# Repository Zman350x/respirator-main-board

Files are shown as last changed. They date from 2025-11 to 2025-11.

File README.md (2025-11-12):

# Respirator Main Board PCB
## Description

Controls the fans of an active respirator, with added user interface and
various indicators. Made for Intro Engineering Design final project, Fall 2025.

## Pictures

Layout:

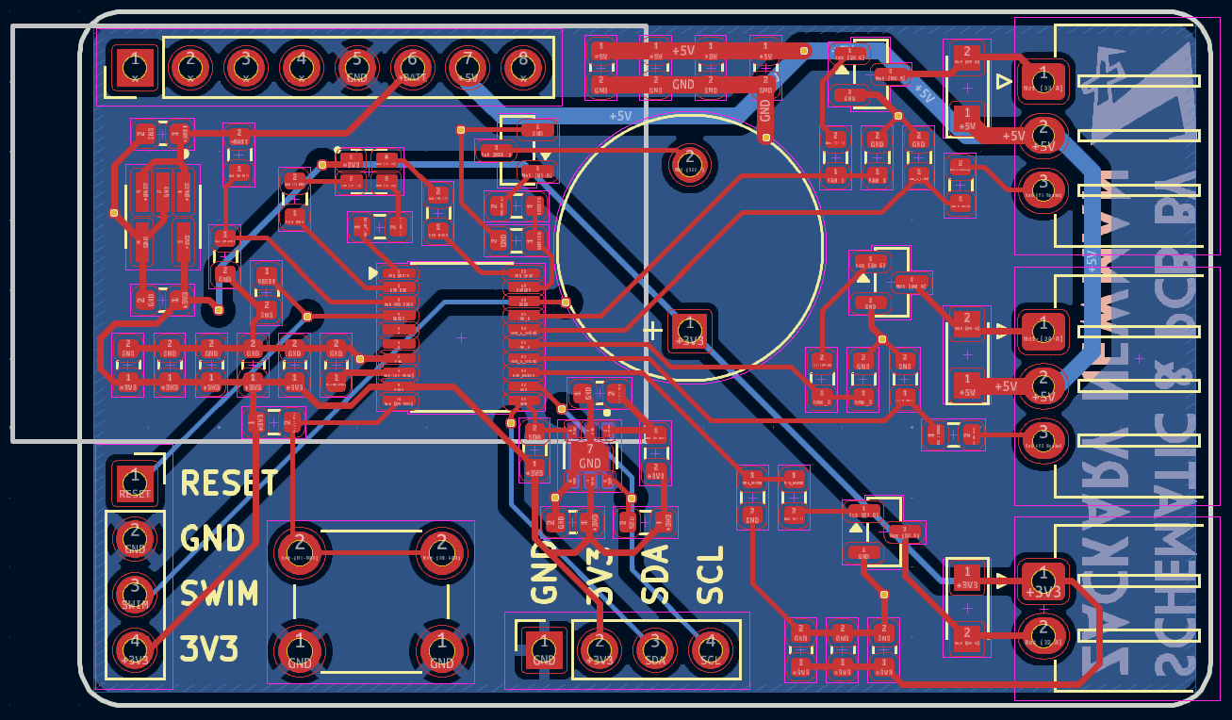
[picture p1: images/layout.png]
Layout


3D Render:

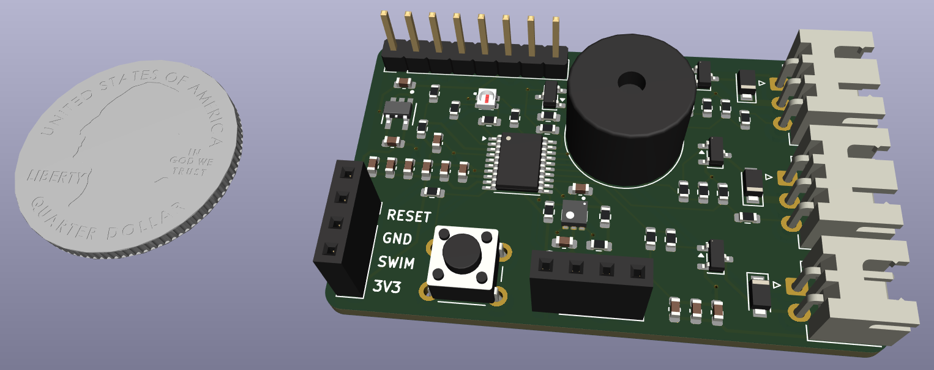
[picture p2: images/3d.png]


Schematic:

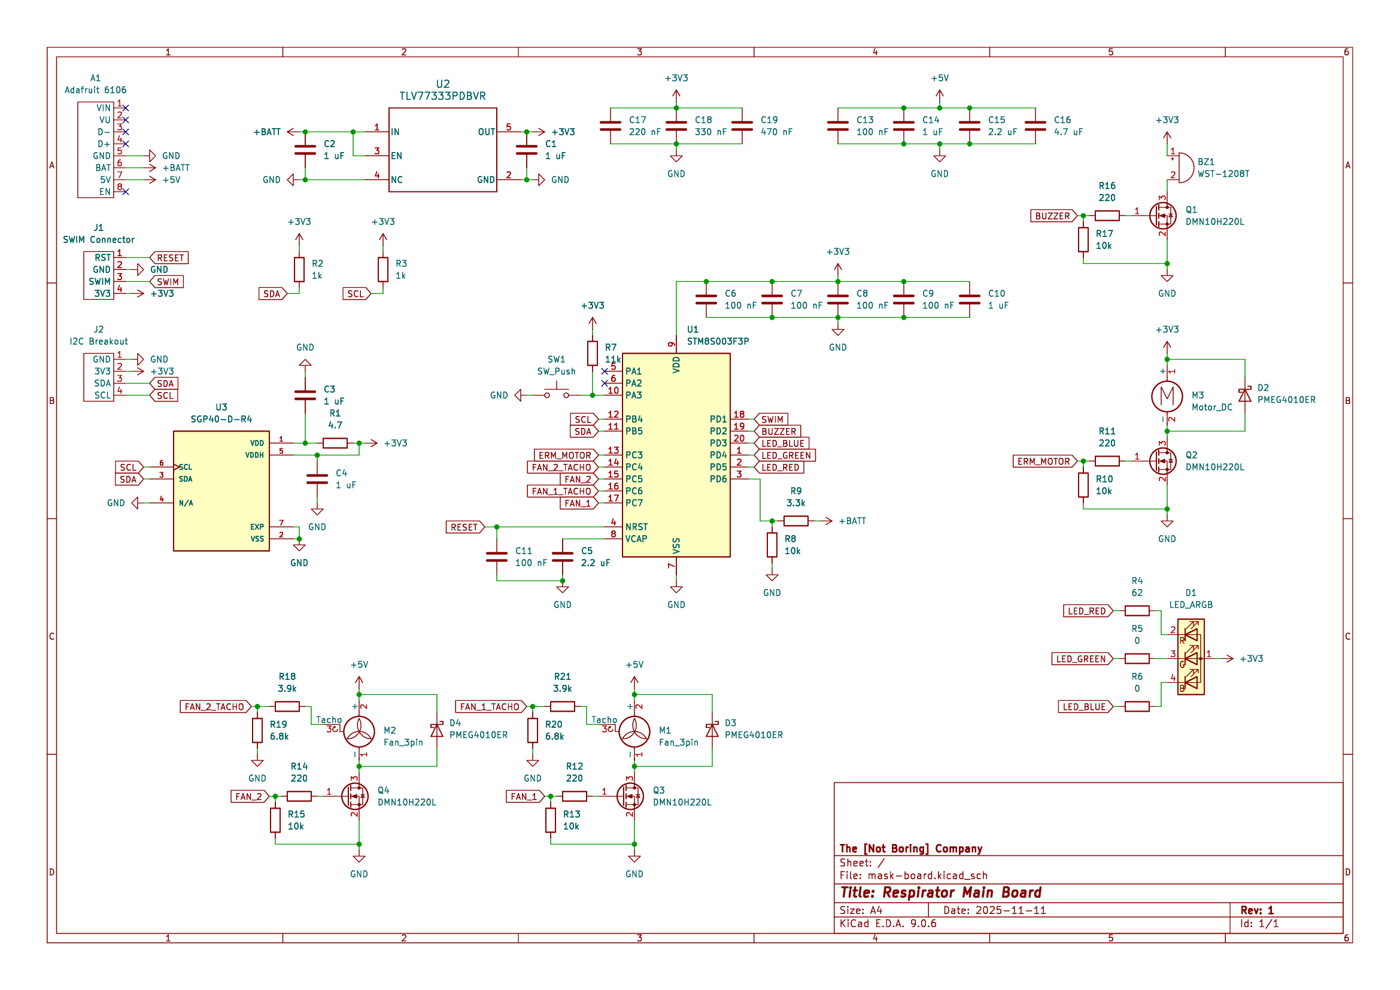
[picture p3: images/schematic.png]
Schematic


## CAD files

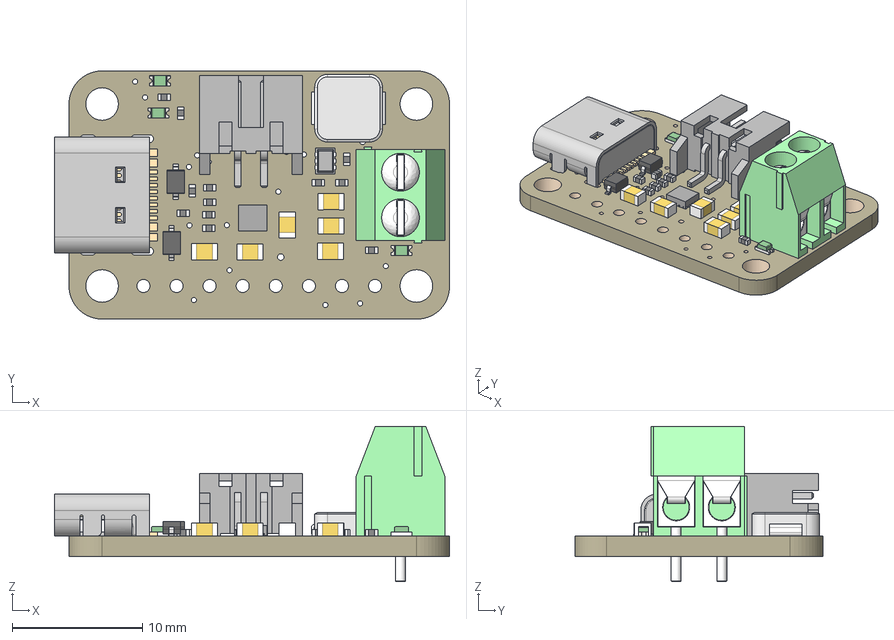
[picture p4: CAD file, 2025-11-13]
6106 BQ25185 5V.step
30.3 x 19.1 x 11.9 mm
Board
USB C
100K x 12
RED x 3
22uF x 6
JST2PH
BQ25185
NSR0320 x 2
TPS61023
1uH
3.5mm 2p

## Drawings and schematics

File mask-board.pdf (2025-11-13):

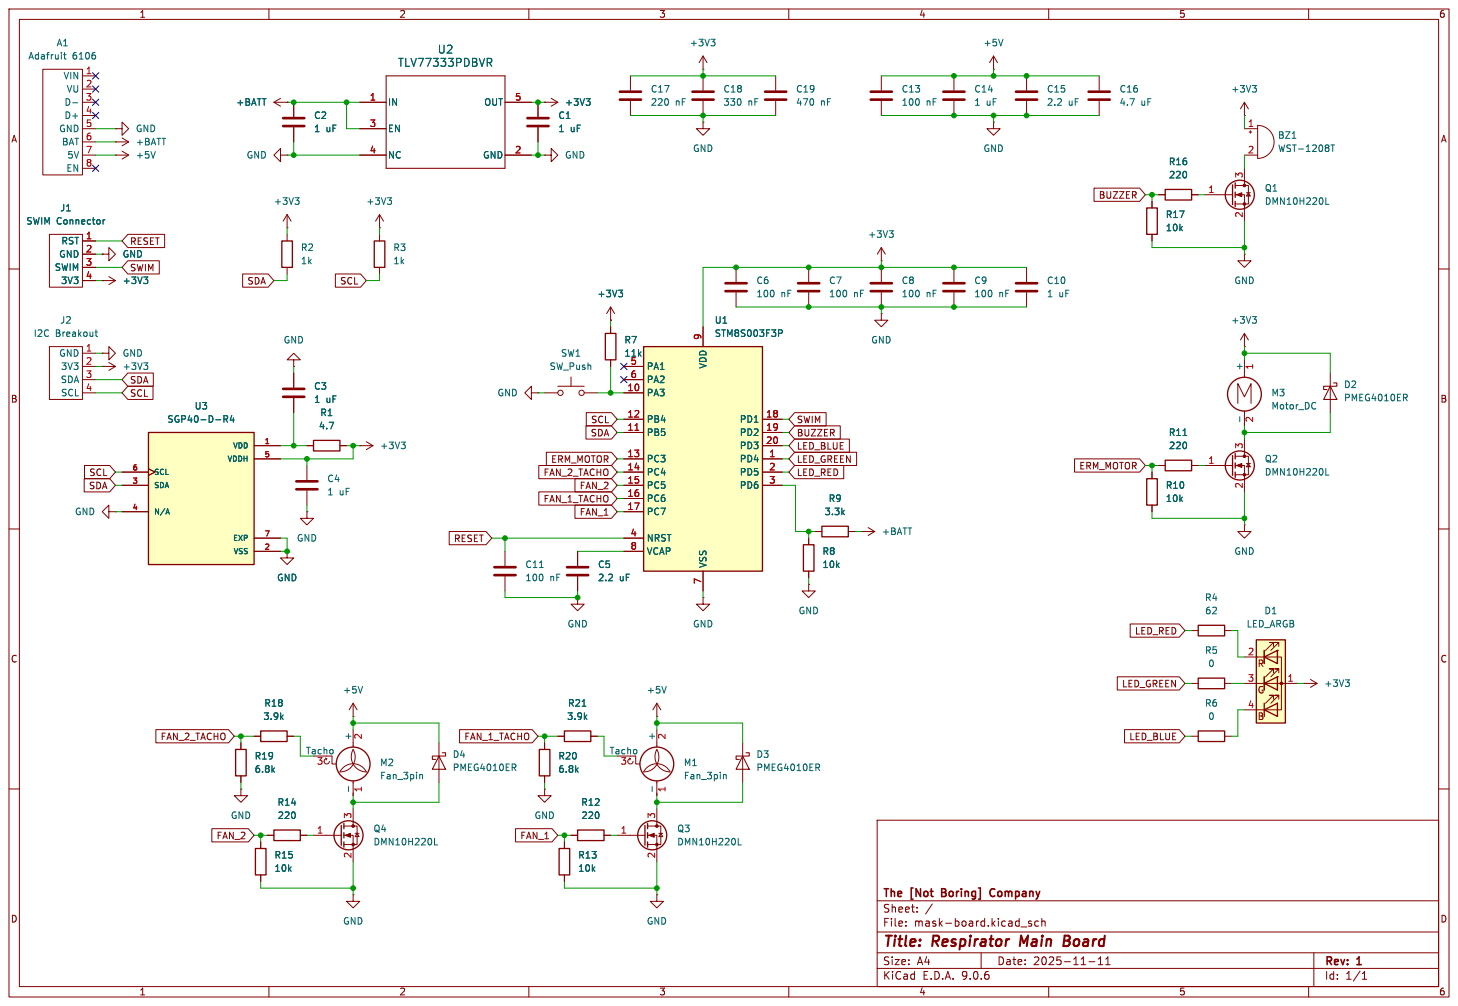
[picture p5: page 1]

Id: 1/1 Title: Respirator Main Board

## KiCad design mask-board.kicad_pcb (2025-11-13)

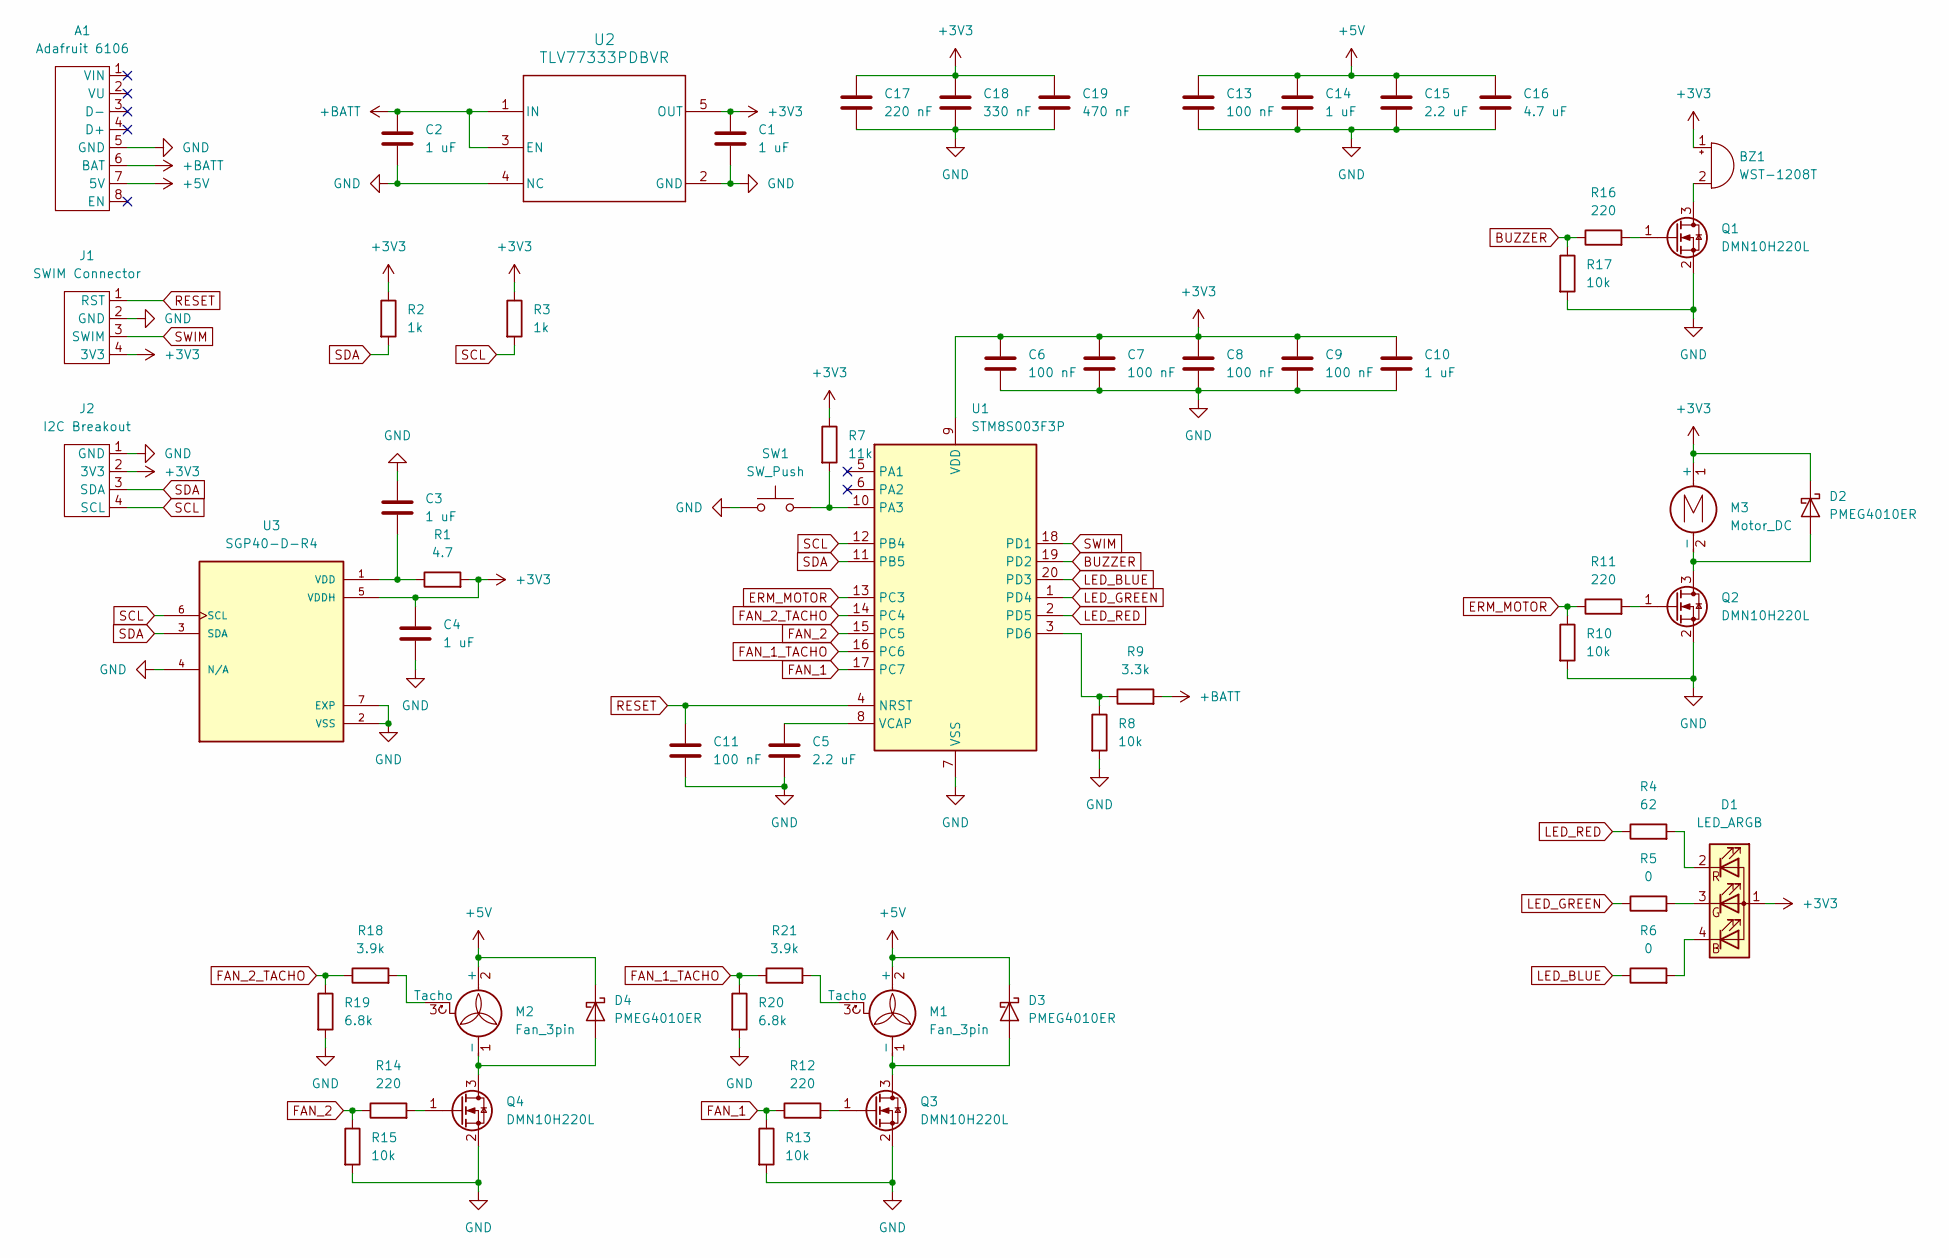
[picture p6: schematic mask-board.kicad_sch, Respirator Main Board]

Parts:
A1: Adafruit 6106; PinHeader_1x08_P2.54mm_Vertical
BZ1: WST-1208T; MagneticBuzzer_ProSignal_ABI-009-RC
C1, C2, C3, C4, C10, C14: 1 uF; C_0603_1608Metric
C5, C15: 2.2 uF; C_0603_1608Metric
C6, C7, C8, C9, C11, C13: 100 nF; C_0603_1608Metric
C16: 4.7 uF; C_0603_1608Metric
C17: 220 nF; C_0603_1608Metric
C18: 330 nF; C_0603_1608Metric
C19: 470 nF; C_0603_1608Metric
D1: LED_ARGB; LED_T2133BGR
D2, D3, D4: PMEG4010ER; Nexperia_CFP3_SOD-123W
J1: SWIM Connector; PinSocket_1x04_P2.54mm_Vertical
J2: I2C Breakout; PinSocket_1x04_P2.54mm_Vertical
M1, M2: Fan_3pin; JST-XH-3-pin
M3: Motor_DC; JST-XH-2-pin
Q1, Q2, Q3, Q4: DMN10H220L; SOT-23
R1: 4.7; R_0603_1608Metric
R2, R3: 1k; R_0603_1608Metric
R4: 62; R_0603_1608Metric
R5, R6: 0; R_0603_1608Metric
R7: 11k; R_0603_1608Metric
R8, R10, R13, R15, R17: 10k; R_0603_1608Metric
R9: 3.3k; R_0603_1608Metric
R11, R12, R14, R16: 220; R_0603_1608Metric
R18, R21: 3.9k; R_0603_1608Metric
R19, R20: 6.8k; R_0603_1608Metric
SW1: SW_Push; SW_PUSH_6mm_H5mm
U1: STM8S003F3P; TSSOP-20_4.4x6.5mm_P0.65mm
U2: TLV77333PDBVR; DBV0005A-IPC_A
U3: SGP40-D-R4; XCDR_SGP40-D-R4; PARTREV 1.2

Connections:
+3V3: BZ1.1 (+), C1.1, C4.1, C6.1, C7.1, C8.1, C9.1, C10.1, C17.1, C18.1, C19.1, D1.1 (A), D2.1 (K), J1.4 (3V3), J2.2 (3V3), M3.1 (+), R1.2, R2.1, R3.1, R7.1, U1.9 (VDD), U2.5 (OUT), U3.5 (VDDH)
+5V: A1.7 (5V), C13.1, C14.1, C15.1, C16.1, D3.1 (K), D4.1 (K), M1.2 (+), M2.2 (+)
+BATT: A1.6 (BAT), C2.1, R9.2, U2.1 (IN), U2.3 (EN)
BUZZER: R16.1, R17.1, U1.19 (PD2)
ERM_MOTOR: R10.1, R11.1, U1.13 (PC3)
FAN_1: R12.1, R13.1, U1.17 (PC7)
FAN_1_TACHO: R20.1, R21.1, U1.16 (PC6)
FAN_2: R14.1, R15.1, U1.15 (PC5)
FAN_2_TACHO: R18.1, R19.1, U1.14 (PC4)
GND: A1.5 (GND), C1.2, C2.2, C3.1, C4.2, C5.2, C6.2, C7.2, C8.2, C9.2, C10.2, C11.2, C13.2, C14.2, C15.2, C16.2, C17.2, C18.2, C19.2, J1.2 (GND), J2.1 (GND), Q1.2 (S), Q2.2 (S), Q3.2 (S), Q4.2 (S), R8.2, R10.2, R13.2, R15.2, R17.2, R19.2, R20.2, SW1.1, U1.7 (VSS), U2.2 (GND), U2.4 (NC), U3.2 (VSS), U3.4 (N/A), U3.7 (EXP)
LED_BLUE: R6.1, U1.20 (PD3)
LED_GREEN: R5.1, U1.1 (PD4)
LED_RED: R4.1, U1.2 (PD5)
unnamed: BZ1.2 (-), Q1.3 (D)
unnamed: D1.4 (BK), R6.2
unnamed: D1.3 (GK), R5.2
unnamed: D1.2 (RK), R4.2
unnamed: D2.2 (A), M3.2 (-), Q2.3 (D)
unnamed: D3.2 (A), M1.1 (-), Q3.3 (D)
unnamed: D4.2 (A), M2.1 (-), Q4.3 (D)
unnamed: M1.3 (Tacho), R21.2
unnamed: M2.3 (Tacho), R18.2
unnamed: Q1.1 (G), R16.2
unnamed: Q2.1 (G), R11.2
unnamed: Q3.1 (G), R12.2
unnamed: Q4.1 (G), R14.2
unnamed: R7.2, SW1.2, U1.10 (PA3)
unnamed: R8.1, R9.1, U1.3 (PD6)
unnamed: C5.1, U1.8 (VCAP)
unnamed: C3.2, R1.1, U3.1 (VDD)
RESET: C11.1, J1.1 (RST), U1.4 (NRST)
SCL: J2.4 (SCL), R3.2, U1.12 (PB4), U3.6 (SCL)
SDA: J2.3 (SDA), R2.2, U1.11 (PB5), U3.3 (SDA)
SWIM: J1.3 (SWIM), U1.18 (PD1)

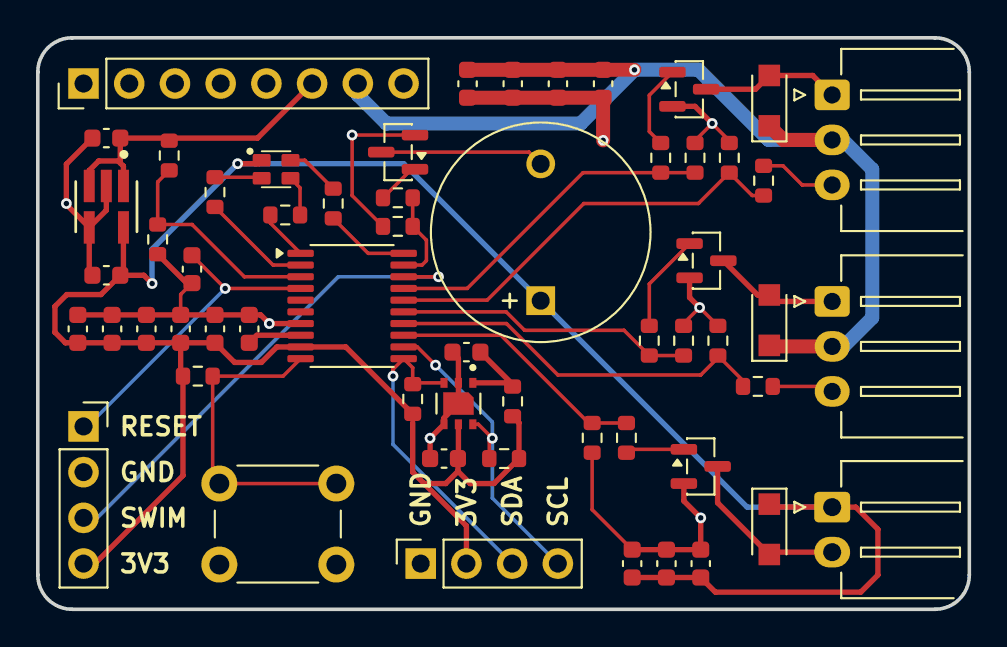
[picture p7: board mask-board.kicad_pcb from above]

Board: 2 copper layers, 51.8 x 31.8 mm, 59 parts (1 on the bottom side), 34 nets.

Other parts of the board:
Ref**: Val**; logo

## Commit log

2025-11-12 Initial commit: PCB version 1
    [mask-board.kicad_pcb, mask-board.kicad_sch]
2025-11-12 Add README and images; Add gitignore
    [mask-board.kicad_pcb]
2025-11-12 Update to board V2
    [mask-board.kicad_pcb, mask-board.kicad_sch]
2025-11-12 Add LED 3D model
    [mask-board.kicad_pcb]
2025-11-12 Update to V3
    [mask-board.kicad_pcb, mask-board.kicad_sch]
2025-11-13 Update to V4; Add quarter for scale in 3D model
    [mask-board.kicad_pcb, mask-board.kicad_sch]
2025-11-13 Fix trace width and cleanup redundant traces
    [mask-board.kicad_pcb]
2025-11-13 Generate gerbers
    [mask-board-B_Cu.gbl, mask-board-B_Mask.gbs, mask-board-B_Paste.gbp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]
2025-11-13 Add 3D model of complete PCB with attached battery controller
    [6106 BQ25185 5V.step]
